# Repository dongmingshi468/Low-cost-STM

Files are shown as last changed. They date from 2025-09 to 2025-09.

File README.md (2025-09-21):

# Low-cost-STM
By using common materials and simple operations, we can build a low-cost scanning tunneling microscope (costing about $400) that achieves atomic-level scanning images. It captures nicely arranged hexagonal structures of highly oriented pyrolytic graphite (HOPG). The 
system can automatically adjust the probe distance within a certain range to get the corresponding tunneling current while avoiding damage to the probe tip from the sample. For the probe tip, we can use a regulated power supply to electrochemically etch tungsten wire for 
high-quality, low-cost testing probes.

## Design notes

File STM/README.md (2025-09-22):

# Scanning Tunneling Microscope (STM) Design

This repository contains the design files for Mechanical Scanning Tunneling Microscope (STM), including Fusion360 CAD files, PCB engineering files, C++ firmware, and the Python software used to control the STM.

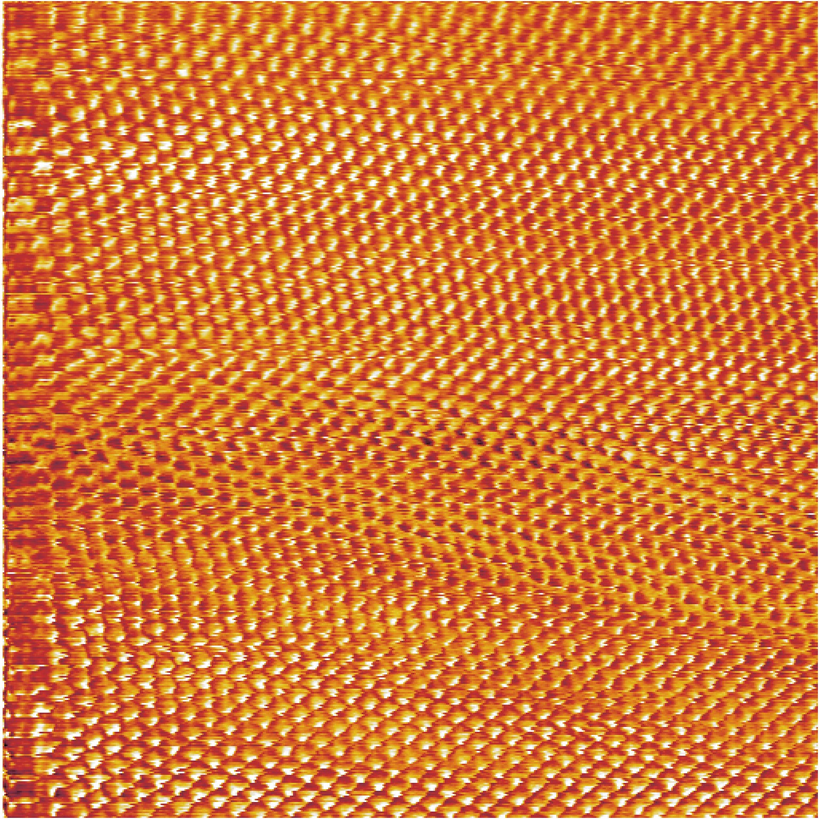
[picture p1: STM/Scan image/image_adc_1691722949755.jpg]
HOPG Image of Carbon Atoms on Graphite Surface Captured by STM

_Image of carbon atoms on the surface of graphite, showing the hexagonal structure of carbon atoms, captured by STM._

## Project Overview

The STM can achieve atomic-level resolution, allowing it to image individual atoms.

The overall design and inspiration for this project were primarily based on Dan Berard's home-built STM project, which you can find here:  
[**[Dan Berard's Home-Built STM]**](https://dberard.com/home-built-stm/)

CAD CAD Files of the STM
_CAD files of the STM, including the STM body and vibration isolation platform._

## Repository Contents

- **Fusion360 CAD Files**: Full 3D models of the STM, including the main STM body and the vibration isolation system.
- **PCB Engineering Files**: PCB designs for the pre-amplifier and control circuit used in the STM.
- **C++ Firmware**: Microcontroller firmware for real-time control of the STM.
- **Python Control Software**: Python software for interfacing with the STM, including GUI control and data processing.

## How It Works

This STM uses a 3D-printed unimorph disk scanner, based on piezoelectric ceramics, for sub-nanometer movement. The sharp tungsten tip moves laterally across the sample's surface while measuring tunneling current to map atomic structures. A Teensy 4.1 microcontroller controls the scanner and collects scan data, while a Python program processes the data to produce high-resolution images of atomic structures.

## Acknowledgments

This project would not have been possible without the work and inspiration from Dan Berard's STM project. A huge thank you for sharing detailed reference materials that helped shape this design.

## Future Work

- **Add BOM List**: A Bill of Materials (BOM) for all the parts needed to build this STM will be added soon.

## Disclaimer

This project is experimental and requires a strong understanding of STM technology, electronics, and 3D printing. Building an STM can be challenging, but if you love pushing the boundaries of what hobbyists can achieve, this project is for you.

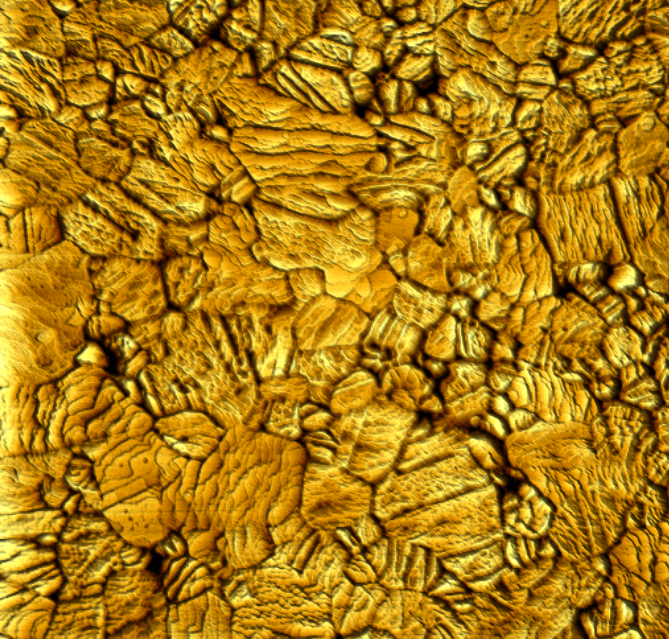
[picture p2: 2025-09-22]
STM/Scan image/image_adc_1436572755.webp

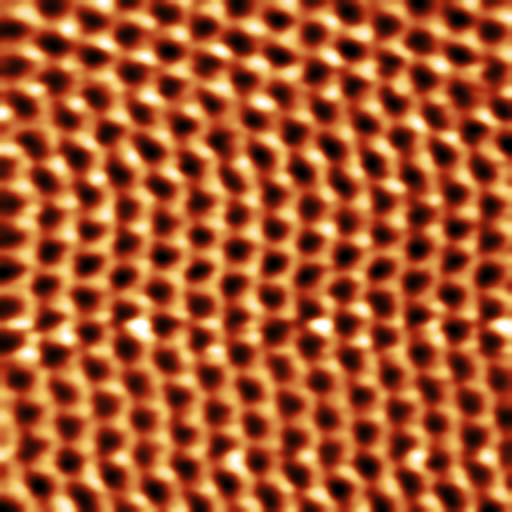
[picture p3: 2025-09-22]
STM/Scan image/image_adc_169172295435.webp

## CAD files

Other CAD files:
STM/CAD/down.dwg
STM/CAD/top.dwg
STM/CAD/STM.f3z

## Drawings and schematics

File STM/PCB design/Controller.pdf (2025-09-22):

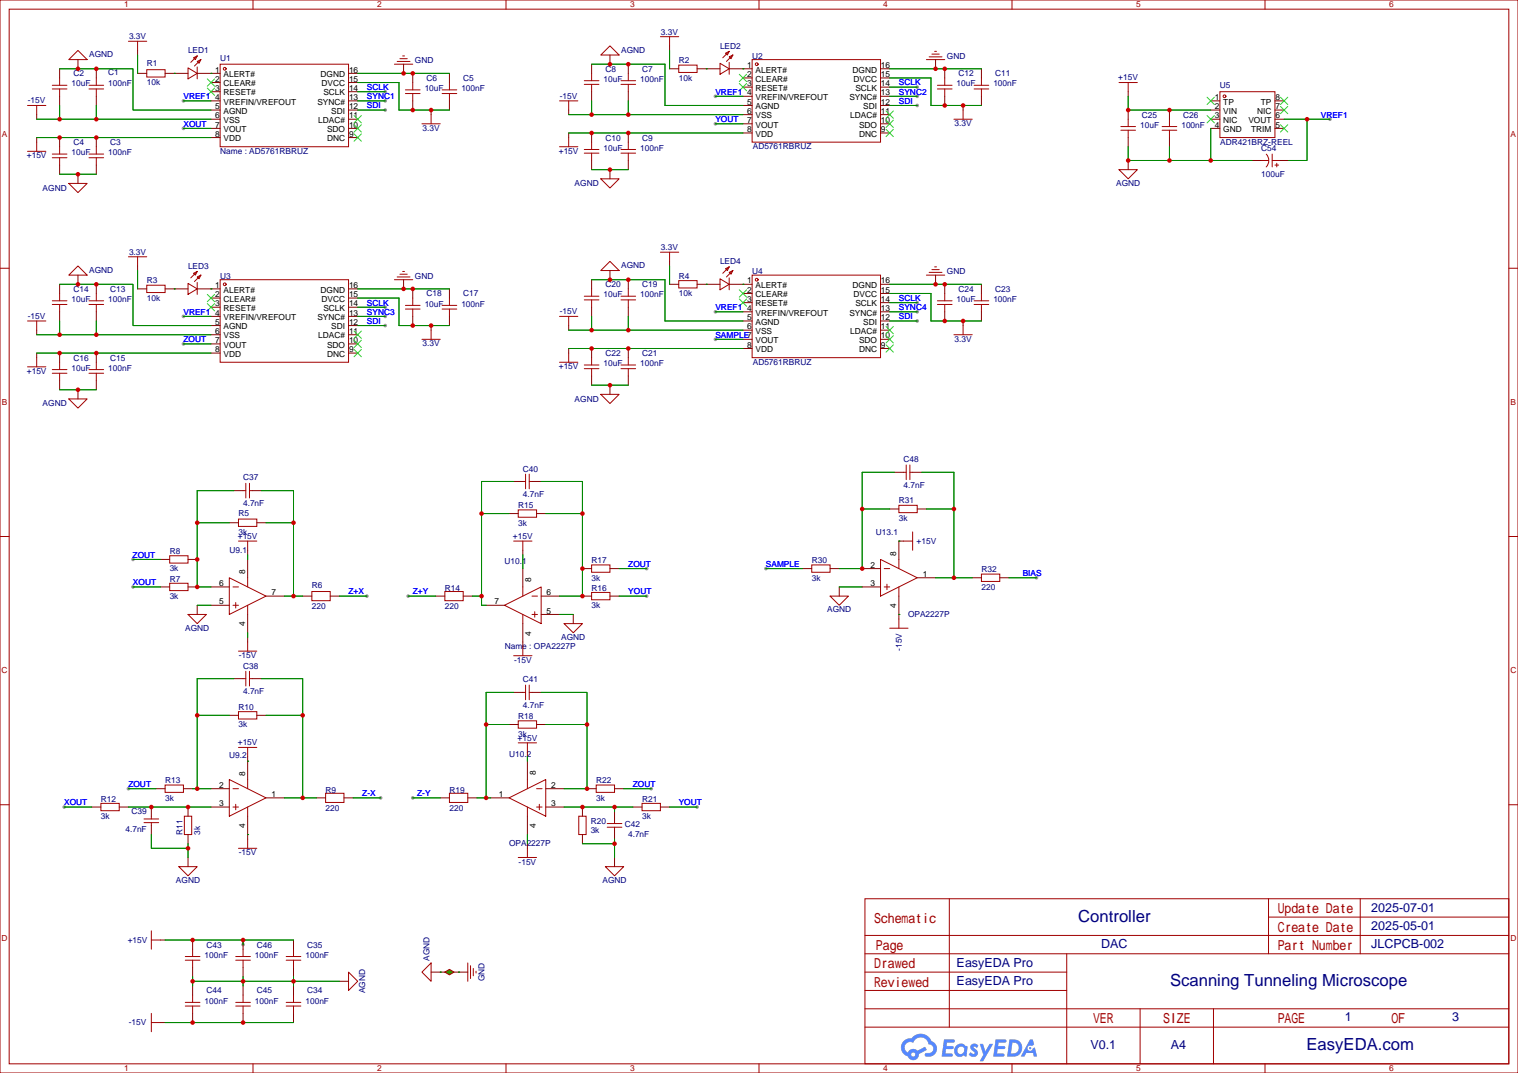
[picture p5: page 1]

SDO 10 LDAC# 11 SDI 12 SYNC# 13 SCLK 14 DVCC 15 DGND 16

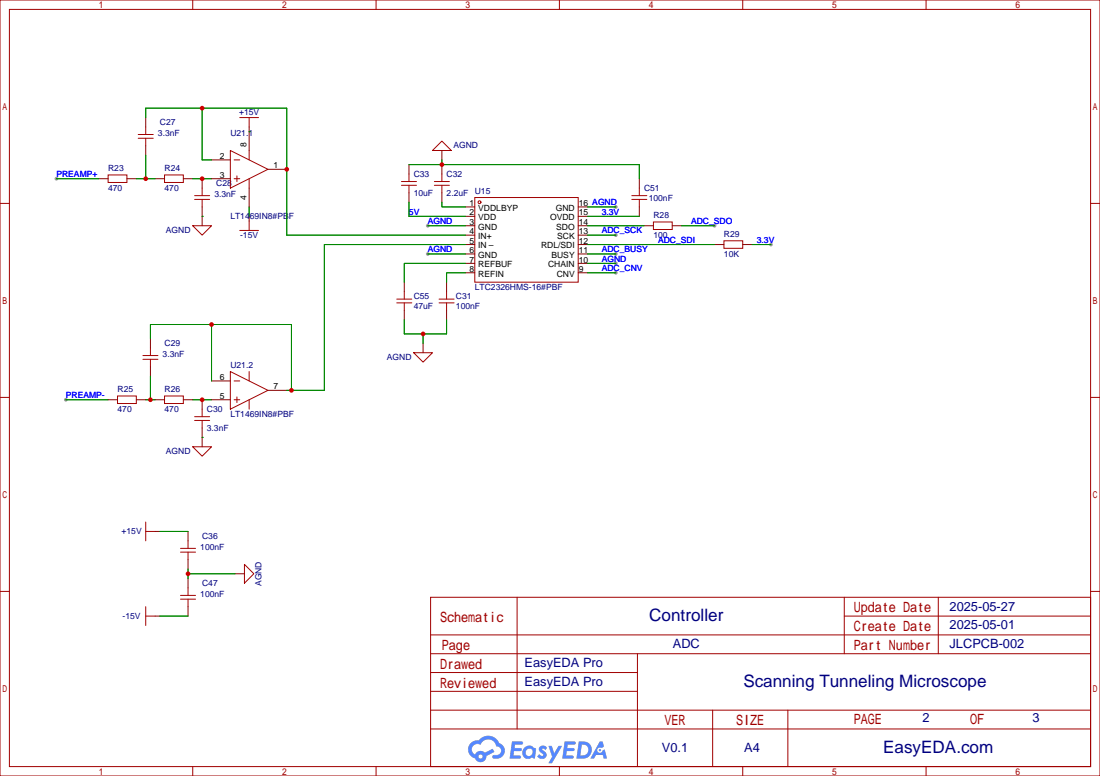
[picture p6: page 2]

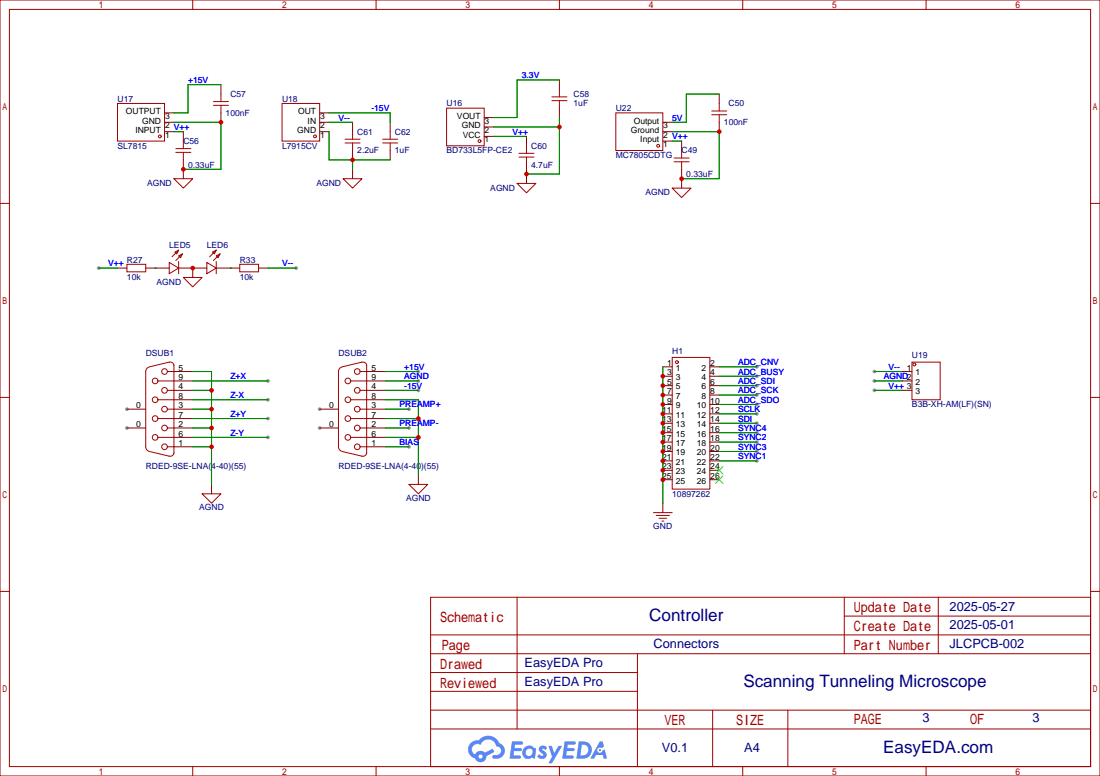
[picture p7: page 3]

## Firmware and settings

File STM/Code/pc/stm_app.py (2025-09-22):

from datetime import datetime
import tkinter as tk
from tkinter import ttk
import numpy as np
import stm_control
import time
import csv
import threading


from matplotlib.backends.backend_tkagg import (
    FigureCanvasTkAgg, NavigationToolbar2Tk)
from matplotlib.figure import Figure
from matplotlib import rcParams
rcParams.update({'figure.autolayout': True})


def save_data_to_file(filename_prefix, data_to_store: list):
    current_time_stamp = datetime.now()
    # getting the timestamp
    ts = int(datetime.timestamp(current_time_stamp)*1000)
    with open(f"{filename_prefix}_{ts}.csv", 'w', newline='') as csvfile:
        # Writing data to a file
        datawriter = csv.writer(csvfile, delimiter=',',
                                quotechar='|', quoting=csv.QUOTE_MINIMAL)
        for data in data_to_store:
            datawriter.writerow(data)


class PlotFrame(ttk.Frame):
    def __init__(self, parent, with_toobar=False,  dpi=100.0, width=300, height=300, *args, **kwargs):
        super().__init__(parent, *args, **kwargs)
        self.figure = Figure(figsize=(width / dpi,
                                      height / dpi), dpi=dpi)

        # Drawing area
        self.canvas = FigureCanvasTkAgg(
            self.figure, master=self)
        self.canvas.draw()
        self.canvas.get_tk_widget().pack(
            side='top', fill='both', expand=True)

        if with_toobar:
            self.toolbar = NavigationToolbar2Tk(
                self.canvas, self)
            self.toolbar.update()
            self.canvas.get_tk_widget().pack(side=tk.TOP, fill=tk.BOTH, expand=1)

    def add_plot(self, label=None, xlabel=None, ylabel=None,):
        self.plot = self.figure.add_subplot(
            111).plot([0, 1], [0, 0], '-', label=label)[0]
        real_time_plot_ax = self.figure.get_axes()[0]
        real_time_plot_ax.set_autoscalex_on(True)
        real_time_plot_ax.set_autoscaley_on(True)
        real_time_plot_ax.legend(loc='upper right')
        if xlabel:
            real_time_plot_ax.set(xlabel=xlabel)
        if ylabel:
            real_time_plot_ax.set(ylabel=ylabel)

    def add_image(self, image):
        self.image = self.figure.add_subplot(
            111).imshow(image, interpolation='none', norm='linear', origin="lower")

    def update_plot(self, x_data, y_data):
        self.plot.set_xdata(x_data)
        self.plot.set_ydata(y_data)
        ax = self.figure.get_axes()[0]
        ax.relim()
        ax.autoscale_view()
        # We need to draw *and* flush
        self.canvas.draw()
        self.canvas.flush_events()

    def update_image(self, image_data, extend=None):
        self.image.set_data(image_data)
        self.image.autoscale()
        if extend:
            self.image.set_extent(extend)
        # ax = self.figure.get_axes()[0]
        # ax.relim()
        # ax.autoscale_view()
        # We need to draw *and* flush
        self.canvas.draw()
        self.canvas.flush_events()

    def save_figure(self, image_path):
        self.figure.savefig(image_path)


class App(tk.Tk):
    def __init__(self):
        super().__init__()

        # Init STM
        # STM configs
        self.stm = stm_control.STM()

        # 修改界面名称为"stm"
        self.wm_title("stm")
        self.baseline_size = 500

        self.image_frame = ttk.Frame(
            self, width=self.baseline_size * 2, height=self.baseline_size * 2)
        self.image_frame.grid(row=0, column=1, padx=5, pady=5)

        # Image frame settings - 减小图形尺寸
        self.real_time_current_plot_frame = PlotFrame(
            self.image_frame, dpi=80.0, with_toobar=True, width=self.baseline_size, height=self.baseline_size)
        self.real_time_current_plot_frame.add_plot(
            label="current", xlabel='time(s)', ylabel='adc')
        self.real_time_current_plot_frame.grid(
            row=0, column=0, padx=5, pady=5)

        self.real_time_steps_plot_frame = PlotFrame(
            self.image_frame, dpi=80.0,  with_toobar=True, width=self.baseline_size, height=self.baseline_size)
        self.real_time_steps_plot_frame.add_plot(label="steps")
        self.real_time_steps_plot_frame.grid(
            row=0, column=1, padx=5, pady=5)

        # Image area for iv curve
        self.iv_curve_frame = PlotFrame(
            self.image_frame, dpi=80.0,  with_toobar=True, width=self.baseline_size, height=self.baseline_size)
        self.iv_curve_frame.add_plot(
            label="IVCurve", xlabel="Bias", ylabel="ADC")
        self.iv_curve_frame.grid(row=1, column=0, padx=5, pady=5)

        # Image area for scan image
        # Image frame settings
        self.scan_dacz_frame = PlotFrame(
            self.image_frame, dpi=80.0, with_toobar=True, width=self.baseline_size, height=self.baseline_size)
        init_image = np.random.rand(10, 10)
        self.scan_dacz_frame.add_image(init_image)
        self.scan_dacz_frame.grid(row=0, column=2, padx=5, pady=5)

        self.scan_adc_frame = PlotFrame(
            self.image_frame, dpi=80.0, with_toobar=True, width=self.baseline_size, height=self.baseline_size)
        init_image = np.random.rand(10, 10)
        self.scan_adc_frame.add_image(init_image)
        self.scan_adc_frame.grid(row=1, column=2, padx=5, pady=5)

        self._update_images()

        # Control pannels
        # Create left and right frames for control and display
        row_number = 0
        self.control_frames = ttk.Frame(
            self, width=350, height=self.baseline_size * 2)
        self.control_frames.grid(
            row=0, column=0, padx=5, pady=5, sticky=tk.NW)

        button_frame = ttk.Frame(self.control_frames)
        button_frame.grid(row=row_number, column=0, sticky=tk.W)

        class _DAC_Control(tk.Frame):
            def __init__(self, parent, text, default_value, cmd_func, convert_func, *args, **kwargs):
                super().__init__(parent, *args, **kwargs)
                self.cmd_func = cmd_func
                self.convert_func = convert_func
                self.input_string_var = tk.StringVar()
                self.input_string_var.set(default_value)
                self.input_entry = tk.Entry(
                    self, textvariable=self.input_string_var, width=10)
                self.input_entry.grid(
                    row=0, column=1, columnspan=1, padx=2, pady=2)

                self.display_var = tk.StringVar()
                self._update_display(default_value)

                self.display = tk.Label(self, textvariable=self.display_var, width=12)
                self.display.grid(row=0, column=2, padx=2, pady=2)
                self.button = ttk.Button(
                    master=self, text=text, command=self.set_value, width=10)
                self.button.grid(row=0, column=0, padx=2, pady=2)

            def _update_display(self, value):
                self.display_var.set(
                    str(self.convert_func(int(value))))

            def set_value(self):
                target = self.input_string_var.get()
                self.cmd_func(int(target))
                self._update_display(target)

        class _ButtonWithEntry(tk.Frame):
            def __init__(self, parent, text, default_value_list, cmd_func, display_list=None, entry_width=8, *args, **kwargs):
                super().__init__(parent, *args, **kwargs)
                self.input_string_var_list = []
                self.input_entry_list = []
                self.cmd_func = cmd_func
                row_button = 1 if display_list else 0
                for i in range(len(default_value_list)):
                    if display_list and display_list[i]:
                        label = ttk.Label(master=self, text=display_list[i], width=6)
                        label.grid(row=0, column=i+1, sticky=tk.W, padx=2, pady=2)
                    input_string_var = tk.StringVar()
                    input_string_var.set(default_value_list[i])
                    input_entry = tk.Entry(
                        self, textvariable=input_string_var, width=entry_width)
                    input_entry.grid(
                        row=row_button, column=i+1, columnspan=1, padx=2, pady=2)
                    self.input_string_var_list.append(input_string_var)
                    self.input_entry_list.append(input_entry)

                button = ttk.Button(
                    master=self, text=text, command=self._set_values, width=12)
                button.grid(row=row_button, column=0, padx=2, pady=2)

            def _set_values(self):
                values = []
                for i in range(len(self.input_string_var_list)):
                    target = self.input_string_var_list[i].get()
                    values.append(target)
                self.cmd_func(*values)

        class _MultipleButtons(tk.Frame):
            def __init__(self, parent, text_list, func_list, *args, **kwargs):
                super().__init__(parent, *args, **kwargs)
                for i in range(len(text_list)):
                    button = ttk.Button(
                        master=self, text=text_list[i], command=func_list[i], width=8)
                    button.grid(row=0, column=i, padx=2, pady=2)

        class _ScanControl(tk.Frame):
            def __init__(self, parent, cmd_func, *args, **kwargs):
                super().__init__(parent, *args, **kwargs)
                var_list = []

                def _create_entry(default_value, row, col):
                    input_string_var = tk.StringVar()
                    input_string_var.set(default_value)
                    input_entry = tk.Entry(
                        self, textvariable=input_string_var, width=8)
                    input_entry.grid(
                        row=row, column=col, padx=2, pady=2)
                    return input_string_var

                for row in range(2):
                    start_var = _create_entry("31768", row, 0)
                    end_var = _create_entry("33768", row, 1)
                    interval_var = _create_entry("512", row, 2)
                    var_list += [start_var, end_var, interval_var]
                sample_num_var = _create_entry("10", 2, 1)
                var_list += [sample_num_var]

                def _set_values():
                    values = []
                    for var in var_list:
                        target = int(var.get())
                        values.append(target)
                    cmd_func(*values)
                # Control Button
                button = ttk.Button(
                    master=self, text="Scan", command=_set_values, width=10)
                button.grid(row=2, column=0, sticky=tk.W, padx=2, pady=2)

        open_frame = _ButtonWithEntry(button_frame,  "Open", [
            "COM7"],  self.stm.open, entry_width=8)
        open_frame.grid(row=row_number, column=0, pady=2, sticky=tk.W)
        row_number += 1

        _stop_rest_clear = _MultipleButtons(button_frame, ["STOP", "Reset", "Clear"], [
                                            self.stm.stop, self.stm.reset, self.stm.clear])
        _stop_rest_clear.grid(row=row_number, column=0,
                              sticky=tk.W, pady=2)
        row_number += 1

        # Set Bias
        bias_control = _DAC_Control(
            button_frame, "Bias", "33314", self.stm.set_bias, stm_control.STM_Status.dac_to_bias_volts)
        bias_control.grid(row=row_number, column=0,
                          sticky=tk.W, pady=2)
        row_number += 1
        dacz_control = _DAC_Control(
            button_frame, "DACZ", "32768", self.stm.set_dacz, stm_control.STM_Status.dac_to_dacz_volts)
        dacz_control.grid(row=row_number, column=0, pady=2,
                          sticky=tk.W)
        row_number += 1
        dacx_control = _DAC_Control(
            button_frame, "DACX", "32768", self.stm.set_dacx, stm_control.STM_Status.dac_to_dacx_volts)
        dacx_control.grid(row=row_number, column=0, pady=2,
                          sticky=tk.W)
        row_number += 1
        dacy_control = _DAC_Control(
            button_frame, "DACY", "32768", self.stm.set_dacy, stm_control.STM_Status.dac_to_dacy_volts)
        dacy_control.grid(row=row_number, column=0, pady=2,
                          sticky=tk.W)
        row_number += 1
        # Set DACZ

        def _set_all_dac():
            bias_control.set_value()
            time.sleep(0.01)
            dacz_control.set_value()
            time.sleep(0.01)
            dacx_control.set_value()
            time.sleep(0.01)
            dacy_control.set_value()
            time.sleep(0.01)

        # Set All DACs
        set_all_dac_button = ttk.Button(
            master=button_frame, text="SetAllDAC", command=_set_all_dac, width=15)
        set_all_dac_button.grid(row=row_number, column=0, pady=2, sticky=tk.W)
        row_number += 1

        # Approach
        # Set Approach
        approach_frame = _ButtonWithEntry(button_frame,  "Approach", [
                                          "500", "1"],  self.stm.approach, entry_width=8)
        approach_frame.grid(row=row_number, column=0, pady=2,
                            sticky=tk.W)
        row_number += 1

        # Create a IV Curve Scan control
        iv_curve_frame = _ButtonWithEntry(button_frame,  "PlotIV", [
                                          "31768", "33768", "10"], self._plot_iv_curve, entry_width=8)
        iv_curve_frame.grid(row=row_number, column=0, pady=2,
                            sticky=tk.W)
        row_number = row_number + 1

        # Store the IV Curve to a file
        def _save_iv_curve(filename_prefix):
            iv_curve_values = self.stm.get_iv_curve()
            x_value = iv_curve_values[::2]
            y_value = iv_curve_values[1::2]
            save_data_to_file(filename_prefix, zip(x_value, y_value))

        save_curve_frame = _ButtonWithEntry(button_frame,  "Save", [
            "./data/iv_curve_"], _save_iv_curve, entry_width=15)
        save_curve_frame.grid(row=row_number, column=0, pady=2,
                              sticky=tk.W)
        row_number = row_number + 1

        # Const Current Mode
        # Setup PID Values
        row_number += 1
        pid_frame = _ButtonWithEntry(button_frame,  "SetPID", [
            "0.0001", "0.0001", "0.0"], self.stm.set_pid, display_list=["Kp", "Ki", "Kd"], entry_width=8)
        pid_frame.grid(row=row_number, column=0, pady=2,
                       sticky=tk.W)
        row_number = row_number + 1
        # Control const current mode
        start_cons_current_frame = _ButtonWithEntry(button_frame,  "ConstCurrentOn", [
            "1000"], self.stm.turn_on_const_current, entry_width=8)
        start_cons_current_frame.grid(row=row_number, column=0, pady=2,
                                      sticky=tk.W)
        row_number = row_number + 1
        stop_cons_current_frame = _ButtonWithEntry(
            button_frame,  "ConstCurrentOFF", [], self.stm.turn_off_const_current, entry_width=8)
        stop_cons_current_frame.grid(row=row_number, column=0, pady=2,
                                     sticky=tk.W)
        row_number = row_number + 1

        # Scan start button
        def _scan_and_plot(*arg):
            scan_thread = threading.Thread(
                target=self.stm.start_scan, args=arg)
            scan_thread.start()
            print("Updated")

        scan_button_frame = _ScanControl(
            button_frame, _scan_and_plot)
        scan_button_frame.grid(row=row_number, column=0, pady=2,
                               sticky=tk.W)
        row_number = row_number + 1

        # Store the Scan Images to files
        def _save_scan_image(image_path_prefix):
            current_time_stamp = datetime.now()
            # getting the timestamp
            ts = int(datetime.timestamp(current_time_stamp)*1000)
            np.savetxt(f"{image_path_prefix}_adc_{ts}.txt", self.stm.scan_adc)
            np.savetxt(f"{image_path_prefix}_dacz_{ts}.txt",
                       self.stm.scan_dacz)
            self.scan_adc_frame.save_figure(
                f"{image_path_prefix}_adc_{ts}.png")
            self.scan_dacz_frame.save_figure(
                f"{image_path_prefix}_dacz_{ts}.png")

        save_image_frame = _ButtonWithEntry(button_frame,  "Save", [
            "./data/image"], _save_scan_image, entry_width=15)
        save_image_frame.grid(row=row_number, column=0, pady=2,
                              sticky=tk.W)
        row_number = row_number + 1

        # Add command and send
        # Create text widget and specify size.
        cmd_text_box = tk.Text(button_frame, height=1, width=20)
        cmd_text_box.grid(row=row_number, column=0, pady=2)

        def _send_cmd():
            cmd = cmd_text_box.get("1.0", tk.END)
            self.stm.send_cmd(cmd)
        row_number += 1
        send_button = ttk.Button(
            master=button_frame, text="Send", command=_send_cmd, width=15)
        send_button.grid(row=row_number, column=0, pady=2)

        # Area for showing status
        self.status_frame = ttk.Frame(self.control_frames)
        self.status_frame.grid(row=1, column=0, pady=5)

        self.status_label = ttk.Label(self.status_frame,
                                      text="No Updates", relief=tk.RAISED, width=40, wraplength=300)
        self.status_label.grid(row=0, column=0, padx=5, pady=5)

        self._update_real_time()
        # Default put the windows to be largest.
        self.state('zoomed')

    def _quit(self):
        self.quit()     # stops mainloop
        self.destroy()  # this is necessary on Windows to prevent
        # Fatal Python Error: PyEval_RestoreThread: NULL tstate

    def _reset(self):
        self.stm.reset()

    def _update_real_time(self):
        if not self.stm.busy:
            status = self.stm.get_status()
            plot_x = [hist.time_millis for hist in self.stm.history]
            self.status_label.config(text=status.to_string())
            max_time = max(plot_x)
            plot_x = [(x - max_time) / self.baseline_size *
                      2.0 for x in plot_x]
            plot_adc = [stm_control.STM_Status.adc_to_amp(
                hist.adc) for hist in self.stm.history]
            plot_steps = [hist.steps for hist in self.stm.history]

            self.real_time_current_plot_frame.update_plot(plot_x, plot_adc)
            self.real_time_steps_plot_frame.update_plot(plot_x, plot_steps)
        self.after(100, self._update_real_time)

    def _update_images(self):
        x_start, x_end, x_resolution, y_start, y_end, y_resolution = self.stm.scan_config
        self.scan_adc_frame.update_image(self.stm.scan_adc, extend=[
            y_start, y_end, x_start, x_end])
        self.scan_dacz_frame.update_image(
            self.stm.scan_dacz, [y_start, y_end, x_start, x_end])
        self.after(100, self._update_images)

    def _plot_iv_curve(self, *args):
        iv_curve_values = self.stm.measure_iv_curve(*args)
        x_value = iv_curve_values[::2]
        y_value = iv_curve_values[1::2]
        current = [stm_control.STM_Status.adc_to_amp(adc) for adc in y_value]
        bias = [stm_control.STM_Status.dac_to_bias_volts(
            dac) for dac in x_value]
        self.iv_curve_frame.update_plot(bias, current)


# If you put root.destroy() here, it will cause an error if the window is
# closed with the window manager.
if __name__ == "__main__":
    app = App()
    app.mainloop()
